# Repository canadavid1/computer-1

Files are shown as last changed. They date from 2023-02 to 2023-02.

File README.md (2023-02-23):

# computer-1
A repository containing documentation, specifications, images and code for my processor built out of discrete 2N7002  transistors.

## Motivation
This project is mostly intended as a learning experience. 

## Directories
### Kicad
Kicad files for all the PCBs used in the project.

NOTICE: some of these have some flaws. Do not rely on these working.
### Assembly
Assorted assembly programs, and the corresponding compiler.
### Emulator
Different levels of emulator for the system.
### Ideas
Ideas for further improvement or additions to the system.

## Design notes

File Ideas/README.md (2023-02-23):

# Ideas
## Extending to 16 bit adressing
Involves adding one register to PC and MARH. Possible problems are jump instructions, as they would not be able to adress all jump-able locations.
## Register rotating
Involves adding a hardware SP (8 byte aligned), and making it such that registers 0-7 are on the stack, and not at locations 0xff0-0xff7. This makes the requirement of pushing and popping values to a semi-software stack much less needed.

To be added: Two registers and INC/DEC circuitry for an SP, and instructions to increment/decrement this. 

- Maybe able to inc/dec using ALU?

- Maybe able to map this SP to a register?

- Should the zero register be moved?
## Proper offset adressing
Currently, loading or storing a value will `or` the register with a four-bit immediate. Make this an offset?

To be added: one adder, two (three if 16 bit adressing) incrementers, some logic

- Maybe: also in JR
## Skip number of words
Currently, skip jumps over one word if the condition is met. Maybe make it jump up to 16 words instead?

To be added: one adder for the lowest register of PC

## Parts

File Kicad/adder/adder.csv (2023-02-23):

Source: | C:\Users\david\OneDrive\Pictures\Documents\KICAD\transistor computer v2\adder\adder.sch
Date: | 23/01/2023 12:58:03
Tool: | Eeschema (5.1.9)-1
Generator: | C:\Program Files\KiCad\bin\scripting\plugins/bom_csv_grouped_by_value.py
Component Count: | 83
Individual Components:
Item | Qty | Reference(s) | Value | LibPart | Footprint | Datasheet
 |  | C0 | C | Device:C | Capacitor_SMD:C_0603_1608Metric_Pad1.08x0.95mm_HandSolder | ~
 |  | D0 | D | Device:D | Diode_SMD:D_SOD-323_HandSoldering | ~
 |  | D1 | D | Device:D | Diode_SMD:D_SOD-323_HandSoldering | ~
 |  | D2 | D | Device:D | Diode_SMD:D_SOD-323_HandSoldering | ~
 |  | D3 | D | Device:D | Diode_SMD:D_SOD-323_HandSoldering | ~
 |  | D4 | D | Device:D | Diode_SMD:D_SOD-323_HandSoldering | ~
 |  | D5 | D | Device:D | Diode_SMD:D_SOD-323_HandSoldering | ~
 |  | D6 | D | Device:D | Diode_SMD:D_SOD-323_HandSoldering | ~
 |  | D7 | D | Device:D | Diode_SMD:D_SOD-323_HandSoldering | ~
 |  | D8 | D | Device:D | Diode_SMD:D_SOD-323_HandSoldering | ~
 |  | D201 | D | Device:D | Diode_SMD:D_SOD-323_HandSoldering | ~
 |  | D202 | D | Device:D | Diode_SMD:D_SOD-323_HandSoldering | ~
 |  | D203 | D | Device:D | Diode_SMD:D_SOD-323_HandSoldering | ~
 |  | D204 | D | Device:D | Diode_SMD:D_SOD-323_HandSoldering | ~
 |  | D205 | D | Device:D | Diode_SMD:D_SOD-323_HandSoldering | ~
 |  | D206 | D | Device:D | Diode_SMD:D_SOD-323_HandSoldering | ~
 |  | D207 | D | Device:D | Diode_SMD:D_SOD-323_HandSoldering | ~
 |  | D208 | D | Device:D | Diode_SMD:D_SOD-323_HandSoldering | ~
 |  | D209 | D | Device:D | Diode_SMD:D_SOD-323_HandSoldering | ~
 |  | D301 | D | Device:D | Diode_SMD:D_SOD-323_HandSoldering | ~
 |  | D302 | D | Device:D | Diode_SMD:D_SOD-323_HandSoldering | ~
 |  | D303 | D | Device:D | Diode_SMD:D_SOD-323_HandSoldering | ~
 |  | D304 | D | Device:D | Diode_SMD:D_SOD-323_HandSoldering | ~
 |  | D305 | D | Device:D | Diode_SMD:D_SOD-323_HandSoldering | ~
 |  | D306 | D | Device:D | Diode_SMD:D_SOD-323_HandSoldering | ~
 |  | D307 | D | Device:D | Diode_SMD:D_SOD-323_HandSoldering | ~
 |  | D308 | D | Device:D | Diode_SMD:D_SOD-323_HandSoldering | ~
 |  | D309 | D | Device:D | Diode_SMD:D_SOD-323_HandSoldering | ~
 |  | D401 | D | Device:D | Diode_SMD:D_SOD-323_HandSoldering | ~
 |  | D402 | D | Device:D | Diode_SMD:D_SOD-323_HandSoldering | ~
 |  | D403 | D | Device:D | Diode_SMD:D_SOD-323_HandSoldering | ~
 |  | D404 | D | Device:D | Diode_SMD:D_SOD-323_HandSoldering | ~
 |  | D405 | D | Device:D | Diode_SMD:D_SOD-323_HandSoldering | ~
 |  | D406 | D | Device:D | Diode_SMD:D_SOD-323_HandSoldering | ~
 |  | D407 | D | Device:D | Diode_SMD:D_SOD-323_HandSoldering | ~
 |  | D408 | D | Device:D | Diode_SMD:D_SOD-323_HandSoldering | ~
 |  | D409 | D | Device:D | Diode_SMD:D_SOD-323_HandSoldering | ~
 |  | Q0 | 2N7002 | Transistor_FET:2N7002 | Package_TO_SOT_SMD:SOT-23 | https://www.onsemi.com/pub/Collateral/NDS7002A-D.PDF
 |  | Q1 | 2N7002 | Transistor_FET:2N7002 | Package_TO_SOT_SMD:SOT-23 | https://www.onsemi.com/pub/Collateral/NDS7002A-D.PDF
 |  | Q2 | 2N7002 | Transistor_FET:2N7002 | Package_TO_SOT_SMD:SOT-23 | https://www.onsemi.com/pub/Collateral/NDS7002A-D.PDF
 |  | Q3 | 2N7002 | Transistor_FET:2N7002 | Package_TO_SOT_SMD:SOT-23 | https://www.onsemi.com/pub/Collateral/NDS7002A-D.PDF
 |  | Q4 | 2N7002 | Transistor_FET:2N7002 | Package_TO_SOT_SMD:SOT-23 | https://www.onsemi.com/pub/Collateral/NDS7002A-D.PDF
 |  | Q5 | 2N7002 | Transistor_FET:2N7002 | Package_TO_SOT_SMD:SOT-23 | https://www.onsemi.com/pub/Collateral/NDS7002A-D.PDF
 |  | Q6 | 2N7002 | Transistor_FET:2N7002 | Package_TO_SOT_SMD:SOT-23 | https://www.onsemi.com/pub/Collateral/NDS7002A-D.PDF
 |  | Q7 | 2N7002 | Transistor_FET:2N7002 | Package_TO_SOT_SMD:SOT-23 | https://www.onsemi.com/pub/Collateral/NDS7002A-D.PDF
 |  | Q8 | 2N7002 | Transistor_FET:2N7002 | Package_TO_SOT_SMD:SOT-23 | https://www.onsemi.com/pub/Collateral/NDS7002A-D.PDF
 |  | Q9 | 2N7002 | Transistor_FET:2N7002 | Package_TO_SOT_SMD:SOT-23 | https://www.onsemi.com/pub/Collateral/NDS7002A-D.PDF
 |  | Q201 | 2N7002 | Transistor_FET:2N7002 | Package_TO_SOT_SMD:SOT-23 | https://www.onsemi.com/pub/Collateral/NDS7002A-D.PDF
 |  | Q202 | 2N7002 | Transistor_FET:2N7002 | Package_TO_SOT_SMD:SOT-23 | https://www.onsemi.com/pub/Collateral/NDS7002A-D.PDF
 |  | Q203 | 2N7002 | Transistor_FET:2N7002 | Package_TO_SOT_SMD:SOT-23 | https://www.onsemi.com/pub/Collateral/NDS7002A-D.PDF
 |  | Q204 | 2N7002 | Transistor_FET:2N7002 | Package_TO_SOT_SMD:SOT-23 | https://www.onsemi.com/pub/Collateral/NDS7002A-D.PDF
 |  | Q205 | 2N7002 | Transistor_FET:2N7002 | Package_TO_SOT_SMD:SOT-23 | https://www.onsemi.com/pub/Collateral/NDS7002A-D.PDF
 |  | Q206 | 2N7002 | Transistor_FET:2N7002 | Package_TO_SOT_SMD:SOT-23 | https://www.onsemi.com/pub/Collateral/NDS7002A-D.PDF
 |  | Q207 | 2N7002 | Transistor_FET:2N7002 | Package_TO_SOT_SMD:SOT-23 | https://www.onsemi.com/pub/Collateral/NDS7002A-D.PDF
 |  | Q208 | 2N7002 | Transistor_FET:2N7002 | Package_TO_SOT_SMD:SOT-23 | https://www.onsemi.com/pub/Collateral/NDS7002A-D.PDF
 |  | Q209 | 2N7002 | Transistor_FET:2N7002 | Package_TO_SOT_SMD:SOT-23 | https://www.onsemi.com/pub/Collateral/NDS7002A-D.PDF
 |  | Q210 | 2N7002 | Transistor_FET:2N7002 | Package_TO_SOT_SMD:SOT-23 | https://www.onsemi.com/pub/Collateral/NDS7002A-D.PDF
 |  | Q301 | 2N7002 | Transistor_FET:2N7002 | Package_TO_SOT_SMD:SOT-23 | https://www.onsemi.com/pub/Collateral/NDS7002A-D.PDF
 |  | Q302 | 2N7002 | Transistor_FET:2N7002 | Package_TO_SOT_SMD:SOT-23 | https://www.onsemi.com/pub/Collateral/NDS7002A-D.PDF
 |  | Q303 | 2N7002 | Transistor_FET:2N7002 | Package_TO_SOT_SMD:SOT-23 | https://www.onsemi.com/pub/Collateral/NDS7002A-D.PDF
 |  | Q304 | 2N7002 | Transistor_FET:2N7002 | Package_TO_SOT_SMD:SOT-23 | https://www.onsemi.com/pub/Collateral/NDS7002A-D.PDF
 |  | Q305 | 2N7002 | Transistor_FET:2N7002 | Package_TO_SOT_SMD:SOT-23 | https://www.onsemi.com/pub/Collateral/NDS7002A-D.PDF
 |  | Q306 | 2N7002 | Transistor_FET:2N7002 | Package_TO_SOT_SMD:SOT-23 | https://www.onsemi.com/pub/Collateral/NDS7002A-D.PDF
 |  | Q307 | 2N7002 | Transistor_FET:2N7002 | Package_TO_SOT_SMD:SOT-23 | https://www.onsemi.com/pub/Collateral/NDS7002A-D.PDF
 |  | Q308 | 2N7002 | Transistor_FET:2N7002 | Package_TO_SOT_SMD:SOT-23 | https://www.onsemi.com/pub/Collateral/NDS7002A-D.PDF
 |  | Q309 | 2N7002 | Transistor_FET:2N7002 | Package_TO_SOT_SMD:SOT-23 | https://www.onsemi.com/pub/Collateral/NDS7002A-D.PDF
 |  | Q310 | 2N7002 | Transistor_FET:2N7002 | Package_TO_SOT_SMD:SOT-23 | https://www.onsemi.com/pub/Collateral/NDS7002A-D.PDF
 |  | Q401 | 2N7002 | Transistor_FET:2N7002 | Package_TO_SOT_SMD:SOT-23 | https://www.onsemi.com/pub/Collateral/NDS7002A-D.PDF
 |  | Q402 | 2N7002 | Transistor_FET:2N7002 | Package_TO_SOT_SMD:SOT-23 | https://www.onsemi.com/pub/Collateral/NDS7002A-D.PDF
 |  | Q403 | 2N7002 | Transistor_FET:2N7002 | Package_TO_SOT_SMD:SOT-23 | https://www.onsemi.com/pub/Collateral/NDS7002A-D.PDF
 |  | Q404 | 2N7002 | Transistor_FET:2N7002 | Package_TO_SOT_SMD:SOT-23 | https://www.onsemi.com/pub/Collateral/NDS7002A-D.PDF
 |  | Q405 | 2N7002 | Transistor_FET:2N7002 | Package_TO_SOT_SMD:SOT-23 | https://www.onsemi.com/pub/Collateral/NDS7002A-D.PDF
 |  | Q406 | 2N7002 | Transistor_FET:2N7002 | Package_TO_SOT_SMD:SOT-23 | https://www.onsemi.com/pub/Collateral/NDS7002A-D.PDF
 |  | Q407 | 2N7002 | Transistor_FET:2N7002 | Package_TO_SOT_SMD:SOT-23 | https://www.onsemi.com/pub/Collateral/NDS7002A-D.PDF
 |  | Q408 | 2N7002 | Transistor_FET:2N7002 | Package_TO_SOT_SMD:SOT-23 | https://www.onsemi.com/pub/Collateral/NDS7002A-D.PDF
 |  | Q409 | 2N7002 | Transistor_FET:2N7002 | Package_TO_SOT_SMD:SOT-23 | https://www.onsemi.com/pub/Collateral/NDS7002A-D.PDF
 |  | Q410 | 2N7002 | Transistor_FET:2N7002 | Package_TO_SOT_SMD:SOT-23 | https://www.onsemi.com/pub/Collateral/NDS7002A-D.PDF
 |  | RN0 | R_Pack04 | Device:R_Pack04 | Resistor_SMD:R_Array_Convex_4x1206 | ~
 |  | RN1 | R_Pack04 | Device:R_Pack04 | Resistor_SMD:R_Array_Convex_4x1206 | ~
 |  | RN2 | R_Pack04 | Device:R_Pack04 | Resistor_SMD:R_Array_Convex_4x1206 | ~
 |  | RN201 | R_Pack04 | Device:R_Pack04 | Resistor_SMD:R_Array_Convex_4x1206 | ~
 |  | RN301 | R_Pack04 | Device:R_Pack04 | Resistor_SMD:R_Array_Convex_4x1206 | ~
 |  | RN401 | R_Pack04 | Device:R_Pack04 | Resistor_SMD:R_Array_Convex_4x1206 | ~
Collated Components:
Item | Qty | Reference(s) | Value | LibPart | Footprint | Datasheet
1 | 1 | C0 | C | Device:C | Capacitor_SMD:C_0603_1608Metric_Pad1.08x0.95mm_HandSolder | ~
2 | 36 | D0, D1, D2, D3, D4, D5, D6, D7, D8, D201, D202, D203, D204, D205, D206, D207, D208, D209, D301, D302, D303, D304, D305, D306, D307, D308, D309, D401, D402, D403, D404, D405, D406, D407, D408, D409 | D | Device:D | Diode_SMD:D_SOD-323_HandSoldering | ~
3 | 40 | Q0, Q1, Q2, Q3, Q4, Q5, Q6, Q7, Q8, Q9, Q201, Q202, Q203, Q204, Q205, Q206, Q207, Q208, Q209, Q210, Q301, Q302, Q303, Q304, Q305, Q306, Q307, Q308, Q309, Q310, Q401, Q402, Q403, Q404, Q405, Q406, Q407, Q408, Q409, Q410 | 2N7002 | Transistor_FET:2N7002 | Package_TO_SOT_SMD:SOT-23 | https://www.onsemi.com/pub/Collateral/NDS7002A-D.PDF
4 | 6 | RN0, RN1, RN2, RN201, RN301, RN401 | R_Pack04 | Device:R_Pack04 | Resistor_SMD:R_Array_Convex_4x1206 | ~

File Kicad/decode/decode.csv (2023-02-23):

Source: | C:\Users\david\OneDrive\Pictures\Documents\KICAD\transistor computer v2\decode\decode.sch
Date: | 23/01/2023 12:58:19
Tool: | Eeschema (5.1.9)-1
Generator: | C:\Program Files\KiCad\bin\scripting\plugins/bom_csv_grouped_by_value.py
Component Count: | 59
Individual Components:
Item | Qty | Reference(s) | Value | LibPart | Footprint | Datasheet
 |  | D0 | D | Device:D | custom:D_SOD-323_HandSoldering | ~
 |  | D1 | D | Device:D | custom:D_SOD-323_HandSoldering | ~
 |  | D2 | D | Device:D | custom:D_SOD-323_HandSoldering | ~
 |  | D3 | D | Device:D | custom:D_SOD-323_HandSoldering | ~
 |  | D4 | D | Device:D | custom:D_SOD-323_HandSoldering | ~
 |  | D5 | D | Device:D | custom:D_SOD-323_HandSoldering | ~
 |  | D6 | D | Device:D | custom:D_SOD-323_HandSoldering | ~
 |  | D7 | D | Device:D | custom:D_SOD-323_HandSoldering | ~
 |  | D10 | D | Device:D | custom:D_SOD-323_HandSoldering | ~
 |  | D11 | D | Device:D | custom:D_SOD-323_HandSoldering | ~
 |  | D12 | D | Device:D | custom:D_SOD-323_HandSoldering | ~
 |  | D13 | D | Device:D | custom:D_SOD-323_HandSoldering | ~
 |  | D14 | D | Device:D | custom:D_SOD-323_HandSoldering | ~
 |  | D15 | D | Device:D | custom:D_SOD-323_HandSoldering | ~
 |  | D16 | D | Device:D | custom:D_SOD-323_HandSoldering | ~
 |  | D17 | D | Device:D | custom:D_SOD-323_HandSoldering | ~
 |  | D20 | D | Device:D | custom:D_SOD-323_HandSoldering | ~
 |  | D21 | D | Device:D | custom:D_SOD-323_HandSoldering | ~
 |  | D22 | D | Device:D | custom:D_SOD-323_HandSoldering | ~
 |  | D23 | D | Device:D | custom:D_SOD-323_HandSoldering | ~
 |  | D24 | D | Device:D | custom:D_SOD-323_HandSoldering | ~
 |  | D25 | D | Device:D | custom:D_SOD-323_HandSoldering | ~
 |  | D26 | D | Device:D | custom:D_SOD-323_HandSoldering | ~
 |  | D27 | D | Device:D | custom:D_SOD-323_HandSoldering | ~
 |  | D30 | D | Device:D | custom:D_SOD-323_HandSoldering | ~
 |  | D31 | D | Device:D | custom:D_SOD-323_HandSoldering | ~
 |  | D32 | D | Device:D | custom:D_SOD-323_HandSoldering | ~
 |  | D33 | D | Device:D | custom:D_SOD-323_HandSoldering | ~
 |  | D34 | D | Device:D | custom:D_SOD-323_HandSoldering | ~
 |  | D35 | D | Device:D | custom:D_SOD-323_HandSoldering | ~
 |  | D36 | D | Device:D | custom:D_SOD-323_HandSoldering | ~
 |  | D37 | D | Device:D | custom:D_SOD-323_HandSoldering | ~
 |  | D40 | D | Device:D | custom:D_SOD-323_HandSoldering | ~
 |  | D41 | D | Device:D | custom:D_SOD-323_HandSoldering | ~
 |  | D42 | D | Device:D | custom:D_SOD-323_HandSoldering | ~
 |  | D43 | D | Device:D | custom:D_SOD-323_HandSoldering | ~
 |  | D44 | D | Device:D | custom:D_SOD-323_HandSoldering | ~
 |  | D45 | D | Device:D | custom:D_SOD-323_HandSoldering | ~
 |  | D46 | D | Device:D | custom:D_SOD-323_HandSoldering | ~
 |  | D47 | D | Device:D | custom:D_SOD-323_HandSoldering | ~
 |  | D50 | D | Device:D | custom:D_SOD-323_HandSoldering | ~
 |  | D51 | D | Device:D | custom:D_SOD-323_HandSoldering | ~
 |  | D52 | D | Device:D | custom:D_SOD-323_HandSoldering | ~
 |  | D53 | D | Device:D | custom:D_SOD-323_HandSoldering | ~
 |  | D54 | D | Device:D | custom:D_SOD-323_HandSoldering | ~
 |  | D55 | D | Device:D | custom:D_SOD-323_HandSoldering | ~
 |  | D56 | D | Device:D | custom:D_SOD-323_HandSoldering | ~
 |  | D57 | D | Device:D | custom:D_SOD-323_HandSoldering | ~
 |  | J0 | Conn_01x04_Male | Connector:Conn_01x04_Male | Connector_PinHeader_2.54mm:PinHeader_1x04_P2.54mm_Vertical | ~
 |  | J1 | Conn_01x04_Male | Connector:Conn_01x04_Male | Connector_PinHeader_2.54mm:PinHeader_1x04_P2.54mm_Vertical | ~
 |  | J2 | Conn_01x06_Male | Connector:Conn_01x06_Male | Connector_PinHeader_2.54mm:PinHeader_1x06_P2.54mm_Vertical | ~
 |  | JP0 | SolderJumper_2_Bridged | Jumper:SolderJumper_2_Bridged | Jumper:SolderJumper-2_P1.3mm_Bridged_RoundedPad1.0x1.5mm | ~
 |  | JP1 | SolderJumper_2_Bridged | Jumper:SolderJumper_2_Bridged | Jumper:SolderJumper-2_P1.3mm_Bridged_RoundedPad1.0x1.5mm | ~
 |  | Q0 | 2N7002 | Transistor_FET:2N7002 | Package_TO_SOT_SMD:SOT-23 | https://www.onsemi.com/pub/Collateral/NDS7002A-D.PDF
 |  | Q1 | 2N7002 | Transistor_FET:2N7002 | Package_TO_SOT_SMD:SOT-23 | https://www.onsemi.com/pub/Collateral/NDS7002A-D.PDF
 |  | Q2 | 2N7002 | Transistor_FET:2N7002 | Package_TO_SOT_SMD:SOT-23 | https://www.onsemi.com/pub/Collateral/NDS7002A-D.PDF
 |  | Q3 | 2N7002 | Transistor_FET:2N7002 | Package_TO_SOT_SMD:SOT-23 | https://www.onsemi.com/pub/Collateral/NDS7002A-D.PDF
 |  | Q4 | 2N7002 | Transistor_FET:2N7002 | Package_TO_SOT_SMD:SOT-23 | https://www.onsemi.com/pub/Collateral/NDS7002A-D.PDF
 |  | Q5 | 2N7002 | Transistor_FET:2N7002 | Package_TO_SOT_SMD:SOT-23 | https://www.onsemi.com/pub/Collateral/NDS7002A-D.PDF
Collated Components:
Item | Qty | Reference(s) | Value | LibPart | Footprint | Datasheet
1 | 48 | D0, D1, D2, D3, D4, D5, D6, D7, D10, D11, D12, D13, D14, D15, D16, D17, D20, D21, D22, D23, D24, D25, D26, D27, D30, D31, D32, D33, D34, D35, D36, D37, D40, D41, D42, D43, D44, D45, D46, D47, D50, D51, D52, D53, D54, D55, D56, D57 | D | Device:D | custom:D_SOD-323_HandSoldering | ~
2 | 2 | J0, J1 | Conn_01x04_Male | Connector:Conn_01x04_Male | Connector_PinHeader_2.54mm:PinHeader_1x04_P2.54mm_Vertical | ~
3 | 1 | J2 | Conn_01x06_Male | Connector:Conn_01x06_Male | Connector_PinHeader_2.54mm:PinHeader_1x06_P2.54mm_Vertical | ~
4 | 2 | JP0, JP1 | SolderJumper_2_Bridged | Jumper:SolderJumper_2_Bridged | Jumper:SolderJumper-2_P1.3mm_Bridged_RoundedPad1.0x1.5mm | ~
5 | 6 | Q0, Q1, Q2, Q3, Q4, Q5 | 2N7002 | Transistor_FET:2N7002 | Package_TO_SOT_SMD:SOT-23 | https://www.onsemi.com/pub/Collateral/NDS7002A-D.PDF

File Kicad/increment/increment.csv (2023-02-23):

Source: | C:\Users\david\OneDrive\Pictures\Documents\KICAD\transistor computer v2\increment\increment.sch
Date: | 23/01/2023 12:58:37
Tool: | Eeschema (5.1.9)-1
Generator: | C:\Program Files\KiCad\bin\scripting\plugins/bom_csv_grouped_by_value.py
Component Count: | 22
Individual Components:
Item | Qty | Reference(s) | Value | LibPart | Footprint | Datasheet
 |  | D1 | D | Device:D | Diode_SMD:D_SOD-323 | ~
 |  | D2 | D | Device:D | Diode_SMD:D_SOD-323 | ~
 |  | D3 | D | Device:D | Diode_SMD:D_SOD-323 | ~
 |  | D4 | D | Device:D | Diode_SMD:D_SOD-323 | ~
 |  | D5 | D | Device:D | Diode_SMD:D_SOD-323 | ~
 |  | D6 | D | Device:D | Diode_SMD:D_SOD-323 | ~
 |  | D7 | D | Device:D | Diode_SMD:D_SOD-323 | ~
 |  | D8 | D | Device:D | Diode_SMD:D_SOD-323 | ~
 |  | J1 | USB_B_Micro | Connector:USB_B_Micro | Connector_USB:USB_Micro-B_Amphenol_10104110_Horizontal | ~
 |  | Q1 | 2N7002 | Transistor_FET:2N7002 | Package_TO_SOT_SMD:SOT-23 | https://www.onsemi.com/pub/Collateral/NDS7002A-D.PDF
 |  | Q2 | 2N7002 | Transistor_FET:2N7002 | Package_TO_SOT_SMD:SOT-23 | https://www.onsemi.com/pub/Collateral/NDS7002A-D.PDF
 |  | Q3 | 2N7002 | Transistor_FET:2N7002 | Package_TO_SOT_SMD:SOT-23 | https://www.onsemi.com/pub/Collateral/NDS7002A-D.PDF
 |  | Q4 | 2N7002 | Transistor_FET:2N7002 | Package_TO_SOT_SMD:SOT-23 | https://www.onsemi.com/pub/Collateral/NDS7002A-D.PDF
 |  | Q5 | 2N7002 | Transistor_FET:2N7002 | Package_TO_SOT_SMD:SOT-23 | https://www.onsemi.com/pub/Collateral/NDS7002A-D.PDF
 |  | Q6 | 2N7002 | Transistor_FET:2N7002 | Package_TO_SOT_SMD:SOT-23 | https://www.onsemi.com/pub/Collateral/NDS7002A-D.PDF
 |  | Q7 | 2N7002 | Transistor_FET:2N7002 | Package_TO_SOT_SMD:SOT-23 | https://www.onsemi.com/pub/Collateral/NDS7002A-D.PDF
 |  | Q8 | 2N7002 | Transistor_FET:2N7002 | Package_TO_SOT_SMD:SOT-23 | https://www.onsemi.com/pub/Collateral/NDS7002A-D.PDF
 |  | Q9 | 2N7002 | Transistor_FET:2N7002 | Package_TO_SOT_SMD:SOT-23 | https://www.onsemi.com/pub/Collateral/NDS7002A-D.PDF
 |  | Q10 | 2N7002 | Transistor_FET:2N7002 | Package_TO_SOT_SMD:SOT-23 | https://www.onsemi.com/pub/Collateral/NDS7002A-D.PDF
 |  | Q11 | 2N7002 | Transistor_FET:2N7002 | Package_TO_SOT_SMD:SOT-23 | https://www.onsemi.com/pub/Collateral/NDS7002A-D.PDF
 |  | Q12 | 2N7002 | Transistor_FET:2N7002 | Package_TO_SOT_SMD:SOT-23 | https://www.onsemi.com/pub/Collateral/NDS7002A-D.PDF
 |  | RN1 | R_Pack04_Split | Device:R_Pack04_Split | Resistor_SMD:R_Array_Convex_4x1206
Collated Components:
Item | Qty | Reference(s) | Value | LibPart | Footprint | Datasheet
1 | 8 | D1, D2, D3, D4, D5, D6, D7, D8 | D | Device:D | Diode_SMD:D_SOD-323 | ~
2 | 1 | J1 | USB_B_Micro | Connector:USB_B_Micro | Connector_USB:USB_Micro-B_Amphenol_10104110_Horizontal | ~
3 | 12 | Q1, Q2, Q3, Q4, Q5, Q6, Q7, Q8, Q9, Q10, Q11, Q12 | 2N7002 | Transistor_FET:2N7002 | Package_TO_SOT_SMD:SOT-23 | https://www.onsemi.com/pub/Collateral/NDS7002A-D.PDF
4 | 1 | RN1 | R_Pack04_Split | Device:R_Pack04_Split | Resistor_SMD:R_Array_Convex_4x1206

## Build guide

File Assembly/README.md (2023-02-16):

# Assembly code and assembler
This directory contains various assembly programs, and the corresponding assembler.
## Programmer's model
The machine is outwardly a RISC mahcine with 15 hardware 16-bit registers, and (for now) 4081 16-bit words of memory. Register zero is permanently 0.

Almost all operations are register-agnostic, with the exception of `jal`, which jumps to the specified location and stores the return address in r15. Avaliable operations are:

The machine has three status bits, which are the `N`egative, `C`arry, and `Z`ero flags. These are set by all arithmetic operations, and also by loads/stores.

Avaliable operations are:

- `add/sub/adc/sbc/and/xor rd,rx,ry` - performs the corresponding arithmetic operation

- `add/sub/adc/sbc/and/xor rd,rx,#imm` - immediate may be any 16-bit value

- `addis/subis rd,rx,#imm` - immediate may be any power of two less than 256. Shorter encoding.

- `ld/st rd,rp,#off` - address is `rp&off`. Note the logical AND, not addition.

- `j/jal ad` - jumps to the 12-bit address. `jal` stores the return address in `r15`

- `jalr rd,rl,#off` - jumps to `rd&off`, storing return address in `rl`

- `in/out ra,p` - takes input (output) from port `p` into register `ra`

- `skp len,#COND` - skips the next `len` bytes depending on flag condition. Len may currently be one of `1` and `2`

There are also several pseudo-instructins:

- `add/sub/adc/sbc/and/xor rd,y/#imm` - `rx`=`rd`

- `addis/subis rd,#imm` - `rx`=`rd`

- `li rd,#val` - `add rd,r0,#val`

- `jr ra` - `jal rd,r0`

- `ret` - `jal r15,r0`

### On `skp` encoding
The `skp` instruction may branch on any combination of `Z`, `N`, and `C`. The control bits multiplex from the 8 bits in `COND`, and branches if corresponding bit is `1`.

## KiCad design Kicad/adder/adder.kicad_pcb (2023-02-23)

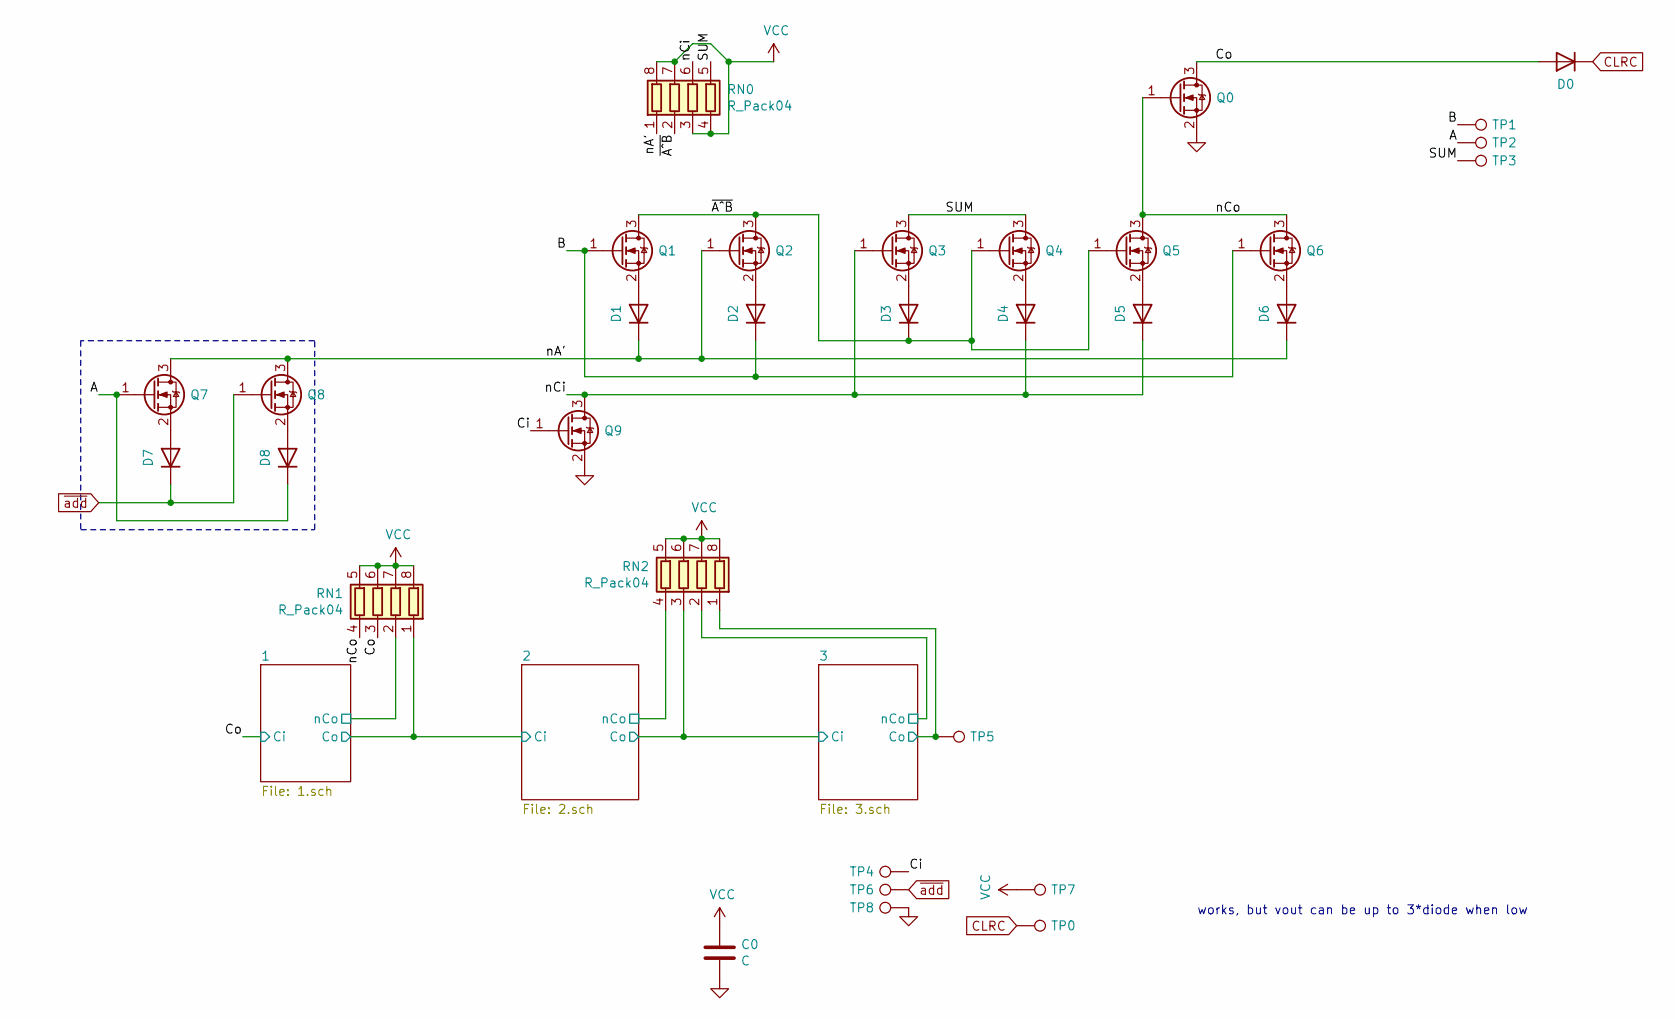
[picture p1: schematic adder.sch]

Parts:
C0: C; C_0603_1608Metric_Pad1.08x0.95mm_HandSolder
D0, D1, D2, D3, D4, D5, D6, D7, D8: D; D_SOD-323_HandSoldering
Q0, Q1, Q2, Q3, Q4, Q5, Q6, Q7, Q8, Q9: 2N7002; SOT-23
RN0, RN1, RN2: R_Pack04; R_Array_Convex_4x1206
TP0, TP1, TP2, TP3, TP4, TP5, TP6, TP7, TP8: Pin_D1.0mm_L10.0mm

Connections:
/1/nCo: RN1.2 (R2.1); also elsewhere on the board
/2/Ci: RN1.1 (R1.1); also elsewhere on the board
/2/nCo: RN2.4 (R4.1); also elsewhere on the board
/3/Ci: RN2.3 (R3.1); also elsewhere on the board
/3/Co: RN2.1 (R1.1), TP5.1; also elsewhere on the board
/3/nCo: RN2.2 (R2.1); also elsewhere on the board
/A: D8.1 (K), Q7.1 (G), TP2.1
/B: D2.1 (K), Q1.1 (G), Q6.1 (G), TP1.1
/Ci: Q9.1 (G), TP4.1
/Co: D0.2 (A), Q0.3 (D), RN1.3 (R3.1); also elsewhere on the board
/SUM: Q3.3 (D), Q4.3 (D), RN0.5 (R4.2), TP3.1
/nA': D1.1 (K), D6.1 (K), Q2.1 (G), Q7.3 (D), Q8.3 (D), RN0.1 (R1.1)
/nCi: D4.1 (K), D5.1 (K), Q3.1 (G), Q9.3 (D), RN0.6 (R3.2)
/nCo: Q0.1 (G), Q5.3 (D), Q6.3 (D), RN1.4 (R4.1)
/~A^B: D3.1 (K), Q1.3 (D), Q2.3 (D), Q4.1 (G), Q5.1 (G), RN0.2 (R2.1)
CLRC: D0.1 (K), TP0.1; also elsewhere on the board
GND: C0.2, Q0.2 (S), Q9.2 (S), TP8.1; also elsewhere on the board
unnamed: D1.2 (A), Q1.2 (S)
unnamed: D2.2 (A), Q2.2 (S)
unnamed: D3.2 (A), Q3.2 (S)
unnamed: D4.2 (A), Q4.2 (S)
unnamed: D5.2 (A), Q5.2 (S)
unnamed: D6.2 (A), Q6.2 (S)
unnamed: D7.2 (A), Q7.2 (S)
unnamed: D8.2 (A), Q8.2 (S)
VCC: C0.1, RN0.3 (R3.1), RN0.4 (R4.1), RN0.7 (R2.2), RN0.8 (R1.2), RN1.5 (R4.2), RN1.6 (R3.2), RN1.7 (R2.2), RN1.8 (R1.2), RN2.5 (R4.2), RN2.6 (R3.2), RN2.7 (R2.2), RN2.8 (R1.2), TP7.1; also elsewhere on the board
~add: D7.1 (K), Q8.1 (G), TP6.1; also elsewhere on the board

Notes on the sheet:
works, but vout can be up to 3*diode when low

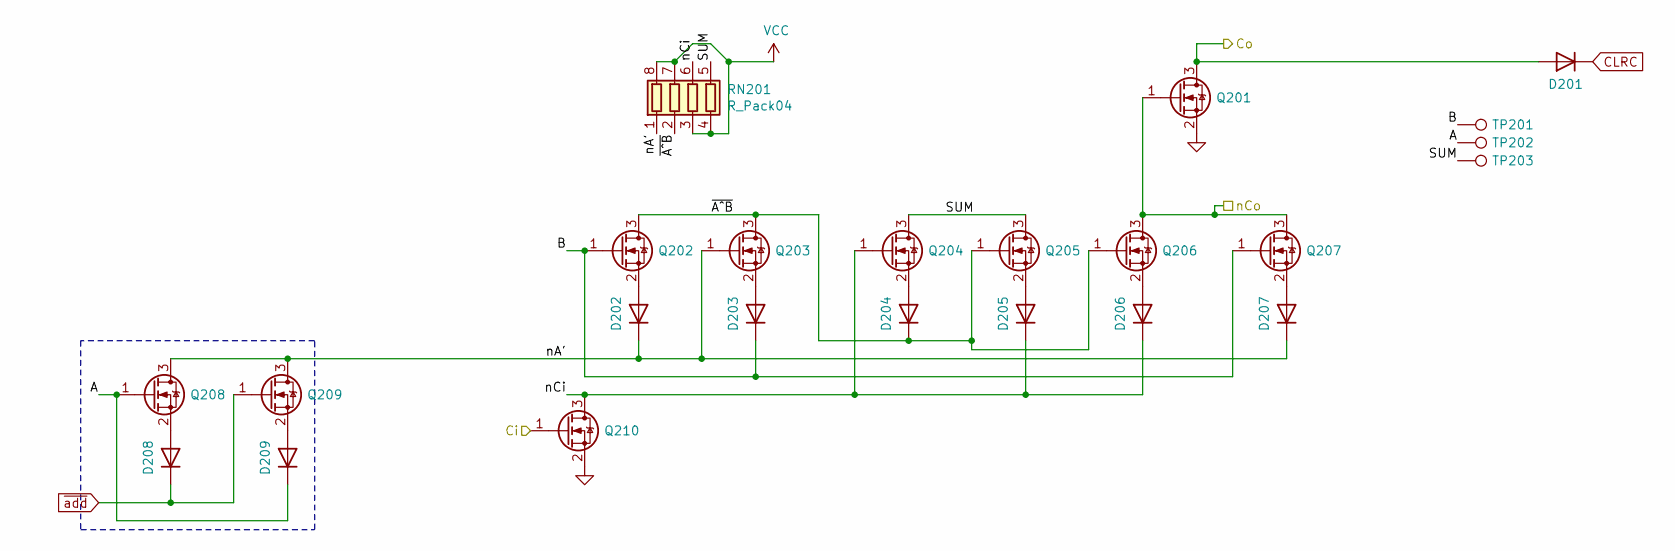
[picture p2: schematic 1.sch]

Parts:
D201, D202, D203, D204, D205, D206, D207, D208, D209: D; D_SOD-323_HandSoldering
Q201, Q202, Q203, Q204, Q205, Q206, Q207, Q208, Q209, Q210: 2N7002; SOT-23
RN201: R_Pack04; R_Array_Convex_4x1206
TP201, TP202, TP203: Pin_D1.0mm_L10.0mm

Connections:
/1/A: D209.1 (K), Q208.1 (G), TP202.1
/1/B: D203.1 (K), Q202.1 (G), Q207.1 (G), TP201.1
/1/SUM: Q204.3 (D), Q205.3 (D), RN201.5 (R4.2), TP203.1
/1/nA': D202.1 (K), D207.1 (K), Q203.1 (G), Q208.3 (D), Q209.3 (D), RN201.1 (R1.1)
/1/nCi: D205.1 (K), D206.1 (K), Q204.1 (G), Q210.3 (D), RN201.6 (R3.2)
/1/nCo: Q201.1 (G), Q206.3 (D), Q207.3 (D); also elsewhere on the board
/1/~A^B: D204.1 (K), Q202.3 (D), Q203.3 (D), Q205.1 (G), Q206.1 (G), RN201.2 (R2.1)
/2/Ci: D201.2 (A), Q201.3 (D); also elsewhere on the board
/Co: Q210.1 (G); also elsewhere on the board
CLRC: D201.1 (K); also elsewhere on the board
GND: Q201.2 (S), Q210.2 (S); also elsewhere on the board
unnamed: D202.2 (A), Q202.2 (S)
unnamed: D203.2 (A), Q203.2 (S)
unnamed: D204.2 (A), Q204.2 (S)
unnamed: D205.2 (A), Q205.2 (S)
unnamed: D206.2 (A), Q206.2 (S)
unnamed: D207.2 (A), Q207.2 (S)
unnamed: D208.2 (A), Q208.2 (S)
unnamed: D209.2 (A), Q209.2 (S)
VCC: RN201.3 (R3.1), RN201.4 (R4.1), RN201.7 (R2.2), RN201.8 (R1.2); also elsewhere on the board
~add: D208.1 (K), Q209.1 (G); also elsewhere on the board

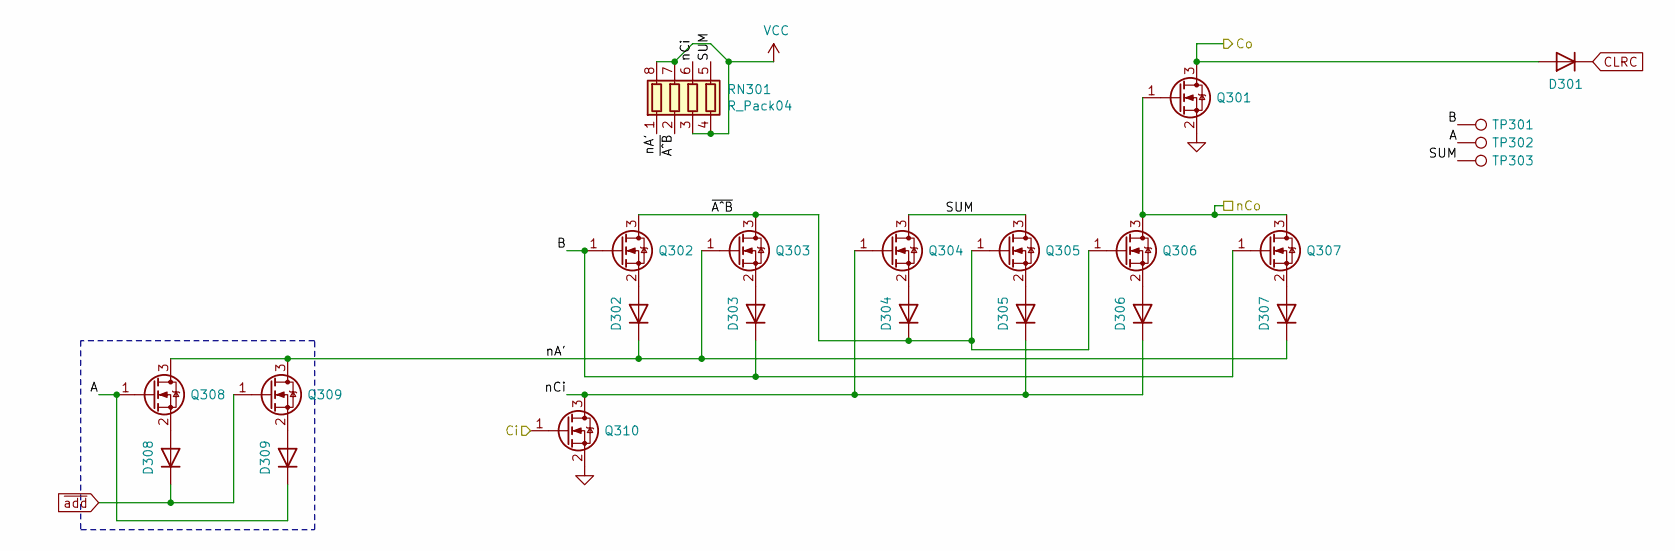
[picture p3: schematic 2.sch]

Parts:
D301, D302, D303, D304, D305, D306, D307, D308, D309: D; D_SOD-323_HandSoldering
Q301, Q302, Q303, Q304, Q305, Q306, Q307, Q308, Q309, Q310: 2N7002; SOT-23
RN301: R_Pack04; R_Array_Convex_4x1206
TP301, TP302, TP303: Pin_D1.0mm_L10.0mm

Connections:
/2/A: D309.1 (K), Q308.1 (G), TP302.1
/2/B: D303.1 (K), Q302.1 (G), Q307.1 (G), TP301.1
/2/Ci: Q310.1 (G); also elsewhere on the board
/2/SUM: Q304.3 (D), Q305.3 (D), RN301.5 (R4.2), TP303.1
/2/nA': D302.1 (K), D307.1 (K), Q303.1 (G), Q308.3 (D), Q309.3 (D), RN301.1 (R1.1)
/2/nCi: D305.1 (K), D306.1 (K), Q304.1 (G), Q310.3 (D), RN301.6 (R3.2)
/2/nCo: Q301.1 (G), Q306.3 (D), Q307.3 (D); also elsewhere on the board
/2/~A^B: D304.1 (K), Q302.3 (D), Q303.3 (D), Q305.1 (G), Q306.1 (G), RN301.2 (R2.1)
/3/Ci: D301.2 (A), Q301.3 (D); also elsewhere on the board
CLRC: D301.1 (K); also elsewhere on the board
GND: Q301.2 (S), Q310.2 (S); also elsewhere on the board
unnamed: D302.2 (A), Q302.2 (S)
unnamed: D303.2 (A), Q303.2 (S)
unnamed: D304.2 (A), Q304.2 (S)
unnamed: D305.2 (A), Q305.2 (S)
unnamed: D306.2 (A), Q306.2 (S)
unnamed: D307.2 (A), Q307.2 (S)
unnamed: D308.2 (A), Q308.2 (S)
unnamed: D309.2 (A), Q309.2 (S)
VCC: RN301.3 (R3.1), RN301.4 (R4.1), RN301.7 (R2.2), RN301.8 (R1.2); also elsewhere on the board
~add: D308.1 (K), Q309.1 (G); also elsewhere on the board

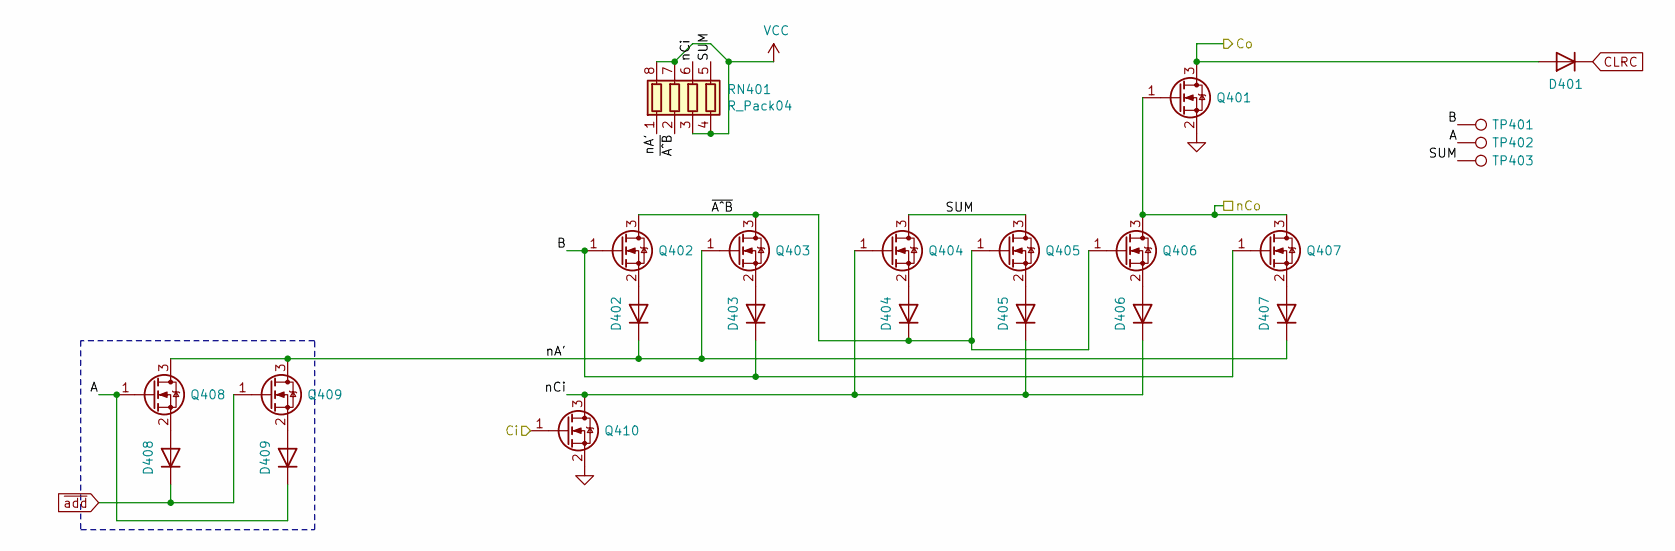
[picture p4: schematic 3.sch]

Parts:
D401, D402, D403, D404, D405, D406, D407, D408, D409: D; D_SOD-323_HandSoldering
Q401, Q402, Q403, Q404, Q405, Q406, Q407, Q408, Q409, Q410: 2N7002; SOT-23
RN401: R_Pack04; R_Array_Convex_4x1206
TP401, TP402, TP403: Pin_D1.0mm_L10.0mm

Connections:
/3/A: D409.1 (K), Q408.1 (G), TP402.1
/3/B: D403.1 (K), Q402.1 (G), Q407.1 (G), TP401.1
/3/Ci: Q410.1 (G); also elsewhere on the board
/3/Co: D401.2 (A), Q401.3 (D); also elsewhere on the board
/3/SUM: Q404.3 (D), Q405.3 (D), RN401.5 (R4.2), TP403.1
/3/nA': D402.1 (K), D407.1 (K), Q403.1 (G), Q408.3 (D), Q409.3 (D), RN401.1 (R1.1)
/3/nCi: D405.1 (K), D406.1 (K), Q404.1 (G), Q410.3 (D), RN401.6 (R3.2)
/3/nCo: Q401.1 (G), Q406.3 (D), Q407.3 (D); also elsewhere on the board
/3/~A^B: D404.1 (K), Q402.3 (D), Q403.3 (D), Q405.1 (G), Q406.1 (G), RN401.2 (R2.1)
CLRC: D401.1 (K); also elsewhere on the board
GND: Q401.2 (S), Q410.2 (S); also elsewhere on the board
unnamed: D402.2 (A), Q402.2 (S)
unnamed: D403.2 (A), Q403.2 (S)
unnamed: D404.2 (A), Q404.2 (S)
unnamed: D405.2 (A), Q405.2 (S)
unnamed: D406.2 (A), Q406.2 (S)
unnamed: D407.2 (A), Q407.2 (S)
unnamed: D408.2 (A), Q408.2 (S)
unnamed: D409.2 (A), Q409.2 (S)
VCC: RN401.3 (R3.1), RN401.4 (R4.1), RN401.7 (R2.2), RN401.8 (R1.2); also elsewhere on the board
~add: D408.1 (K), Q409.1 (G); also elsewhere on the board

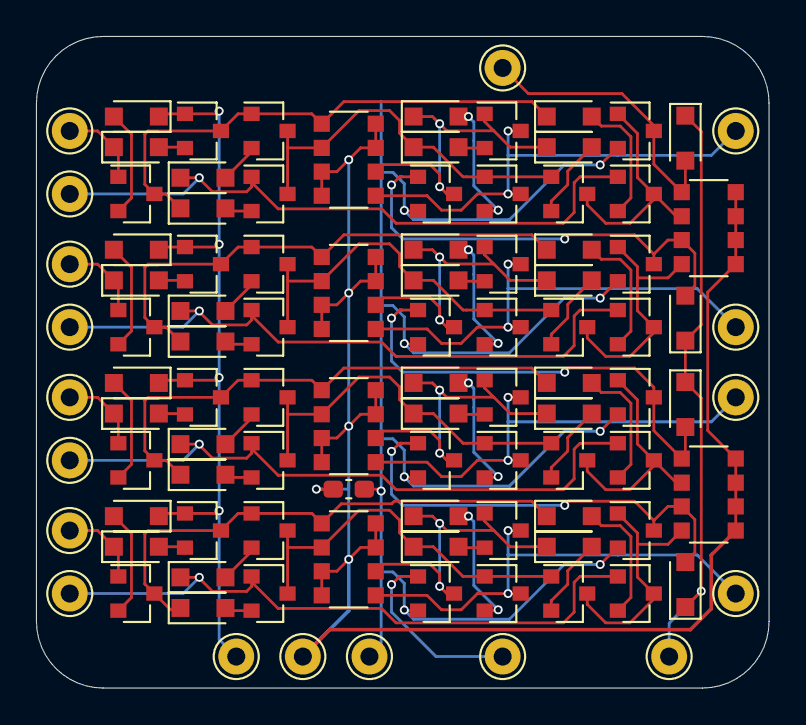
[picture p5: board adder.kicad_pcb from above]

Board: 2 copper layers, 40.7 x 36.2 mm, 101 parts (0 on the bottom side), 69 nets.

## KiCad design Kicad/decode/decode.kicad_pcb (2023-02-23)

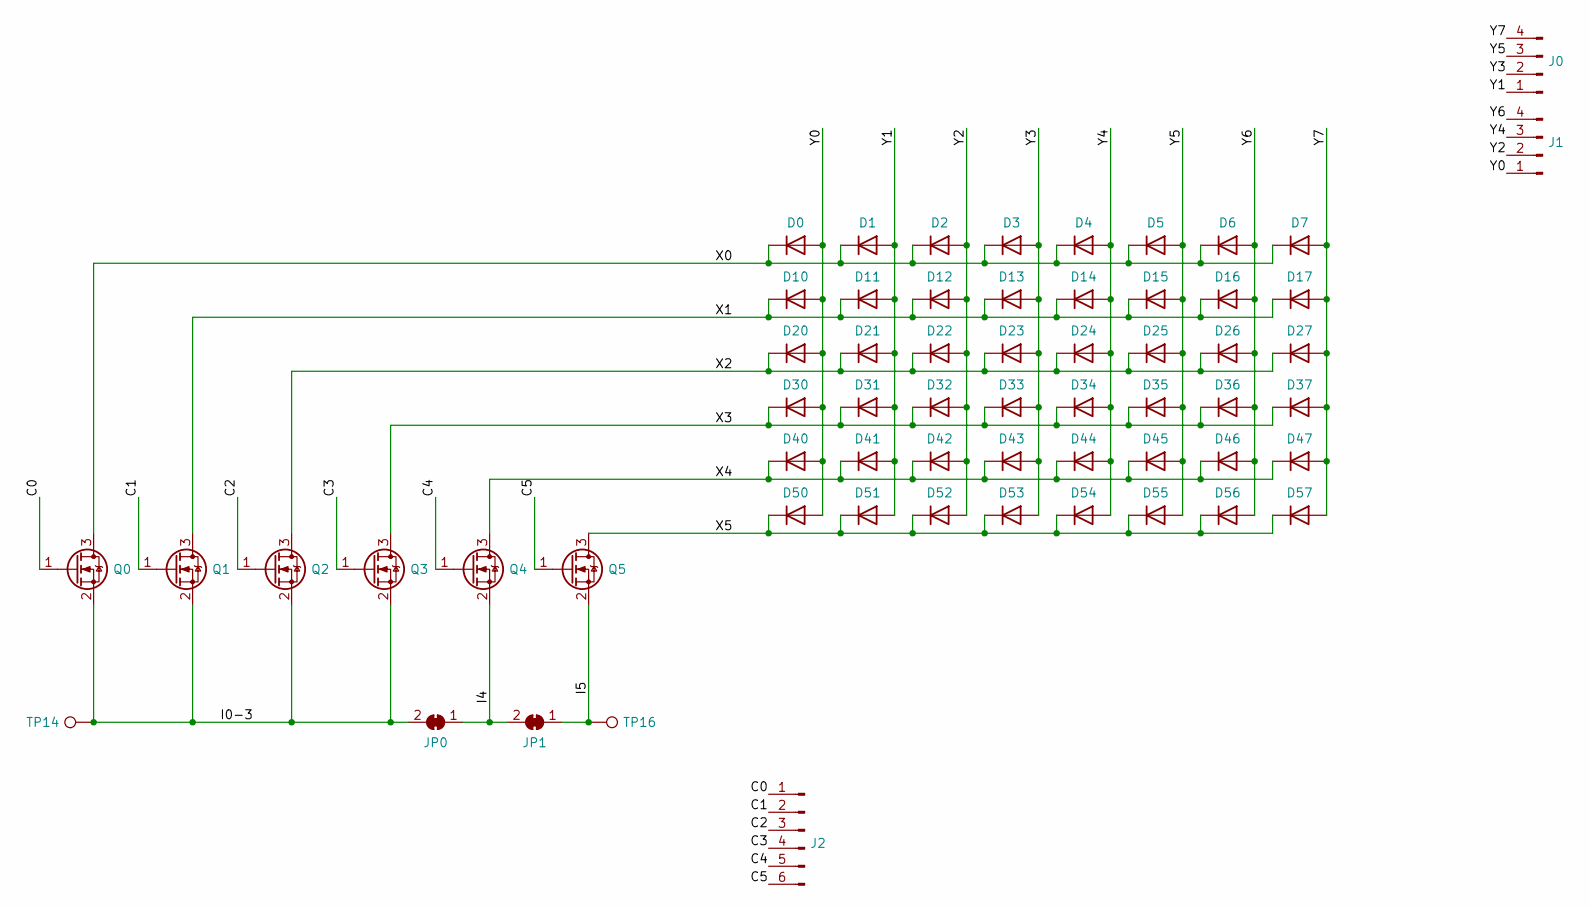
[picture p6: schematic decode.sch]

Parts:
D0, D1, D2, D3, D4, D5, D6, D7, D10, D11, D12, D13, D14, D15, D16, D17, D20, D21, D22, D23, D24, D25, D26, D27, D30, D31, D32, D33, D34, D35, D36, D37, D40, D41, D42, D43, D44, D45, D46, D47, D50, D51, D52, D53, D54, D55, D56, D57: D; D_SOD-323_HandSoldering
J0, J1: Conn_01x04_Male; PinHeader_1x04_P2.54mm_Vertical
J2: Conn_01x06_Male; PinHeader_1x06_P2.54mm_Vertical
JP0, JP1: SolderJumper_2_Bridged; SolderJumper-2_P1.3mm_Bridged_RoundedPad1.0x1.5mm
Q0, Q1, Q2, Q3, Q4, Q5: 2N7002; SOT-23
TP14, TP16: TestPoint; Pin_D1.0mm_L10.0mm

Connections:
/C0: J2.1, Q0.1 (G)
/C1: J2.2, Q1.1 (G)
/C2: J2.3, Q2.1 (G)
/C3: J2.4, Q3.1 (G)
/C4: J2.5, Q4.1 (G)
/C5: J2.6, Q5.1 (G)
/I0-3: JP0.2 (B), Q0.2 (S), Q1.2 (S), Q2.2 (S), Q3.2 (S), TP14.1
/I4: JP0.1 (A), JP1.2 (B), Q4.2 (S)
/I5: JP1.1 (A), Q5.2 (S), TP16.1
/X0: D0.1 (K), D1.1 (K), D2.1 (K), D3.1 (K), D4.1 (K), D5.1 (K), D6.1 (K), D7.1 (K), Q0.3 (D)
/X1: D10.1 (K), D11.1 (K), D12.1 (K), D13.1 (K), D14.1 (K), D15.1 (K), D16.1 (K), D17.1 (K), Q1.3 (D)
/X2: D20.1 (K), D21.1 (K), D22.1 (K), D23.1 (K), D24.1 (K), D25.1 (K), D26.1 (K), D27.1 (K), Q2.3 (D)
/X3: D30.1 (K), D31.1 (K), D32.1 (K), D33.1 (K), D34.1 (K), D35.1 (K), D36.1 (K), D37.1 (K), Q3.3 (D)
/X4: D40.1 (K), D41.1 (K), D42.1 (K), D43.1 (K), D44.1 (K), D45.1 (K), D46.1 (K), D47.1 (K), Q4.3 (D)
/X5: D50.1 (K), D51.1 (K), D52.1 (K), D53.1 (K), D54.1 (K), D55.1 (K), D56.1 (K), D57.1 (K), Q5.3 (D)
/Y0: D0.2 (A), D10.2 (A), D20.2 (A), D30.2 (A), D40.2 (A), D50.2 (A), J1.1
/Y1: D1.2 (A), D11.2 (A), D21.2 (A), D31.2 (A), D41.2 (A), D51.2 (A), J0.1
/Y2: D2.2 (A), D12.2 (A), D22.2 (A), D32.2 (A), D42.2 (A), D52.2 (A), J1.2
/Y3: D3.2 (A), D13.2 (A), D23.2 (A), D33.2 (A), D43.2 (A), D53.2 (A), J0.2
/Y4: D4.2 (A), D14.2 (A), D24.2 (A), D34.2 (A), D44.2 (A), D54.2 (A), J1.3
/Y5: D5.2 (A), D15.2 (A), D25.2 (A), D35.2 (A), D45.2 (A), D55.2 (A), J0.3
/Y6: D6.2 (A), D16.2 (A), D26.2 (A), D36.2 (A), D46.2 (A), D56.2 (A), J1.4
/Y7: D7.2 (A), D17.2 (A), D27.2 (A), D37.2 (A), D47.2 (A), D57.2 (A), J0.4

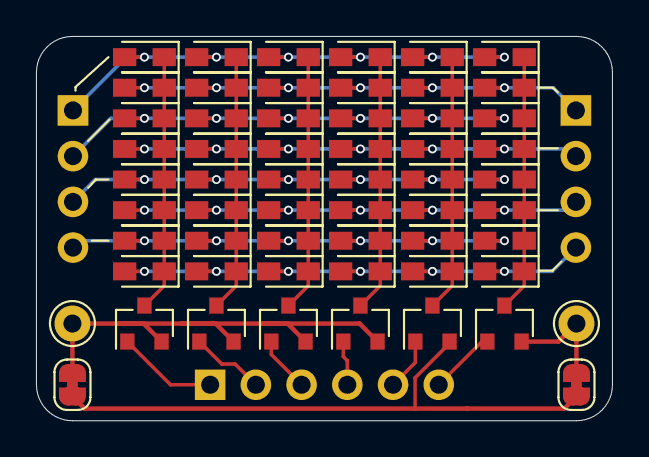
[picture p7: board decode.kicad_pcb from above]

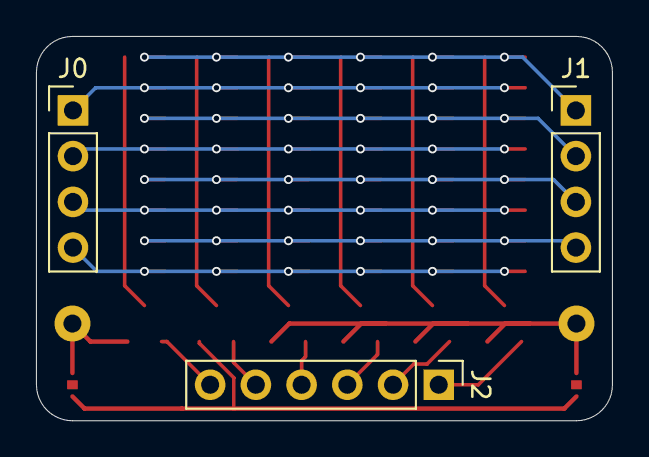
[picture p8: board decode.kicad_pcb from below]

Board: 2 copper layers, 32.0 x 21.3 mm, 61 parts (3 on the bottom side), 23 nets.

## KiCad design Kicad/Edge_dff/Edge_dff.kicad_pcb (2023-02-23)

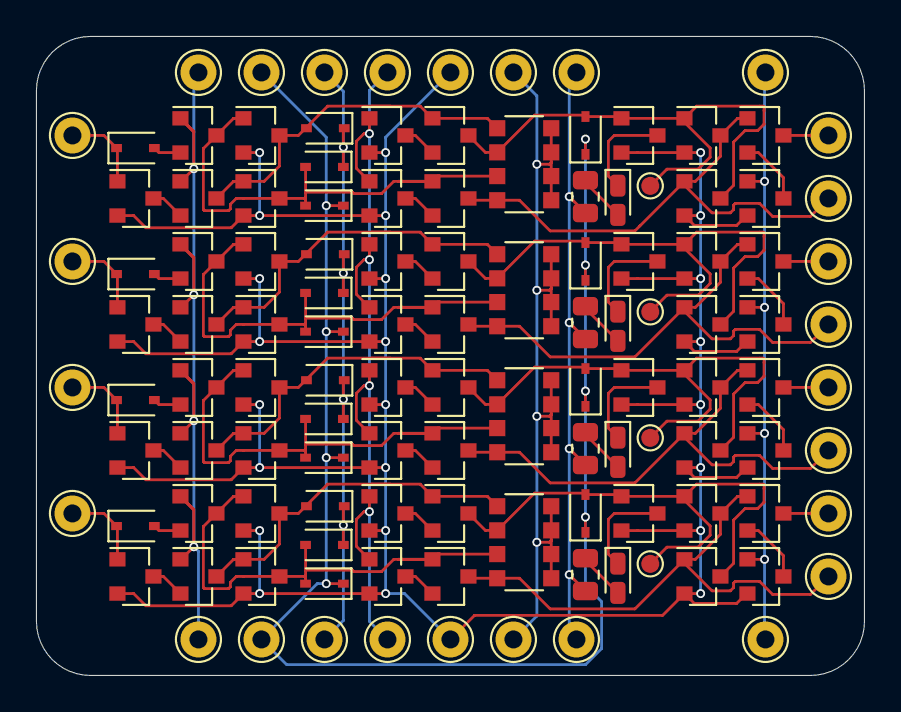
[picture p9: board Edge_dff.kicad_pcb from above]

Board: 2 copper layers, 46.0 x 35.5 mm, 120 parts (0 on the bottom side), 60 nets.

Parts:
D201, D202, D203, D204, D205, D301, D302, D303, D304, D305, D401, D402, D403, D404, D405, D501, D502, D503, D504, D505: D; D_SOD-323
D206, D306, D406, D506: LED; LED_0603_1608Metric_Castellated
Q201, Q202, Q203, Q204, Q205, Q206, Q207, Q208, Q209, Q210, Q211, Q212, Q213, Q214, Q301, Q302, Q303, Q304, Q305, Q306, Q307, Q308, Q309, Q310, Q311, Q312, Q313, Q314, Q401, Q402, Q403, Q404, Q405, Q406, Q407, Q408, Q409, Q410, Q411, Q412, Q413, Q414, Q501, Q502, Q503, Q504, Q505, Q506, Q507, Q508, Q509, Q510, Q511, Q512, Q513, Q514: 2N7002; SOT-23
R201, R301, R401, R501: R; R_0805_2012Metric
RN201, RN301, RN401, RN501: R_Pack04; R_Array_Convex_4x1206
TP102, TP103, TP104, TP105, TP106, TP107, TP108, TP110, TP112, TP113, TP114, TP115, TP116, TP117, TP118, TP120, TP201, TP202, TP203, TP301, TP302, TP303, TP401, TP402, TP403, TP501, TP502, TP503: Pin_D1.0mm_L10.0mm
TP204, TP304, TP404, TP504: TestPoint_Pad_D1.0mm

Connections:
/one/B0: D301.1, Q303.1, TP301.1
/one/B0': Q313.3, TP302.1
/one/I0: D303.2, D304.2, Q301.3, Q304.1, Q305.3, Q306.1, RN301.3
/one/I0': D302.2, Q302.3, Q304.3, Q305.1, Q308.1, RN301.1
/one/Q0: D305.2, Q308.3, Q310.1, Q311.3, Q312.1, RN301.2, TP304.1
/one/Q0': Q306.3, Q310.3, Q311.1, Q313.1, RN301.4, TP303.1
/three/B0: D501.1, Q503.1, TP501.1
/three/B0': Q513.3, TP502.1
/three/I0: D503.2, D504.2, Q501.3, Q504.1, Q505.3, Q506.1, RN501.3
/three/I0': D502.2, Q502.3, Q504.3, Q505.1, Q508.1, RN501.1
/three/Q0: D505.2, Q508.3, Q510.1, Q511.3, Q512.1, RN501.2, TP504.1
/three/Q0': Q506.3, Q510.3, Q511.1, Q513.1, RN501.4, TP503.1
/two/B0: D401.1, Q403.1, TP401.1
/two/B0': Q413.3, TP402.1
/two/I0: D403.2, D404.2, Q401.3, Q404.1, Q405.3, Q406.1, RN401.3
/two/I0': D402.2, Q402.3, Q404.3, Q405.1, Q408.1, RN401.1
/two/Q0: D405.2, Q408.3, Q410.1, Q411.3, Q412.1, RN401.2, TP404.1
/two/Q0': Q406.3, Q410.3, Q411.1, Q413.1, RN401.4, TP403.1
/zero/B0: D201.1, Q203.1, TP201.1
/zero/B0': Q213.3, TP202.1
/zero/I0: D203.2, D204.2, Q201.3, Q204.1, Q205.3, Q206.1, RN201.3
/zero/I0': D202.2, Q202.3, Q204.3, Q205.1, Q208.1, RN201.1
/zero/Q0: D205.2, Q208.3, Q210.1, Q211.3, Q212.1, RN201.2, TP204.1
/zero/Q0': Q206.3, Q210.3, Q211.1, Q213.1, RN201.4, TP203.1
E: D202.1, D203.1, D302.1, D303.1, D402.1, D403.1, D502.1, D503.1, TP106.1, TP116.1
GND: Q203.2, Q204.2, Q205.2, Q207.2, Q209.2, Q210.2, Q211.2, Q212.2, Q214.2, Q303.2, Q304.2, Q305.2, Q307.2, Q309.2, Q310.2, Q311.2, Q312.2, Q314.2, Q403.2, Q404.2, Q405.2, Q407.2, Q409.2, Q410.2, Q411.2, Q412.2, Q414.2, Q503.2, Q504.2, Q505.2, Q507.2, Q509.2, Q510.2, Q511.2, Q512.2, Q514.2, TP110.1, TP120.1
unnamed: D201.2, Q201.2
unnamed: D206.1, Q212.3
unnamed: D206.2, R201.2
unnamed: D301.2, Q301.2
unnamed: D306.1, Q312.3
unnamed: D306.2, R301.2
unnamed: D401.2, Q401.2
unnamed: D406.1, Q412.3
unnamed: D406.2, R401.2
unnamed: D501.2, Q501.2
unnamed: D506.1, Q512.3
unnamed: D506.2, R501.2
unnamed: Q202.2, Q203.3
unnamed: Q206.2, Q207.3
unnamed: Q208.2, Q209.3
unnamed: Q213.2, Q214.3
unnamed: Q302.2, Q303.3
unnamed: Q306.2, Q307.3
unnamed: Q308.2, Q309.3
unnamed: Q313.2, Q314.3
unnamed: Q402.2, Q403.3
unnamed: Q406.2, Q407.3
unnamed: Q408.2, Q409.3
unnamed: Q413.2, Q414.3
unnamed: Q502.2, Q503.3
unnamed: Q506.2, Q507.3
unnamed: Q508.2, Q509.3
unnamed: Q513.2, Q514.3
VCC: RN201.5, RN201.6, RN201.7, RN201.8, RN301.5, RN301.6, RN301.7, RN301.8, RN401.5, RN401.6, RN401.7, RN401.8, RN501.5, RN501.6, RN501.7, RN501.8, TP108.1, TP118.1
Vdrive: R201.1, R301.1, R401.1, R501.1, TP107.1, TP117.1
phi1: Q201.1, Q202.1, Q301.1, Q302.1, Q401.1, Q402.1, Q501.1, Q502.1, TP104.1, TP114.1
phi2: Q207.1, Q209.1, Q307.1, Q309.1, Q407.1, Q409.1, Q507.1, Q509.1, TP103.1, TP113.1
~OE: Q214.1, Q314.1, Q414.1, Q514.1, TP102.1, TP112.1
~reset: D204.1, D205.1, D304.1, D305.1, D404.1, D405.1, D504.1, D505.1, TP105.1, TP115.1

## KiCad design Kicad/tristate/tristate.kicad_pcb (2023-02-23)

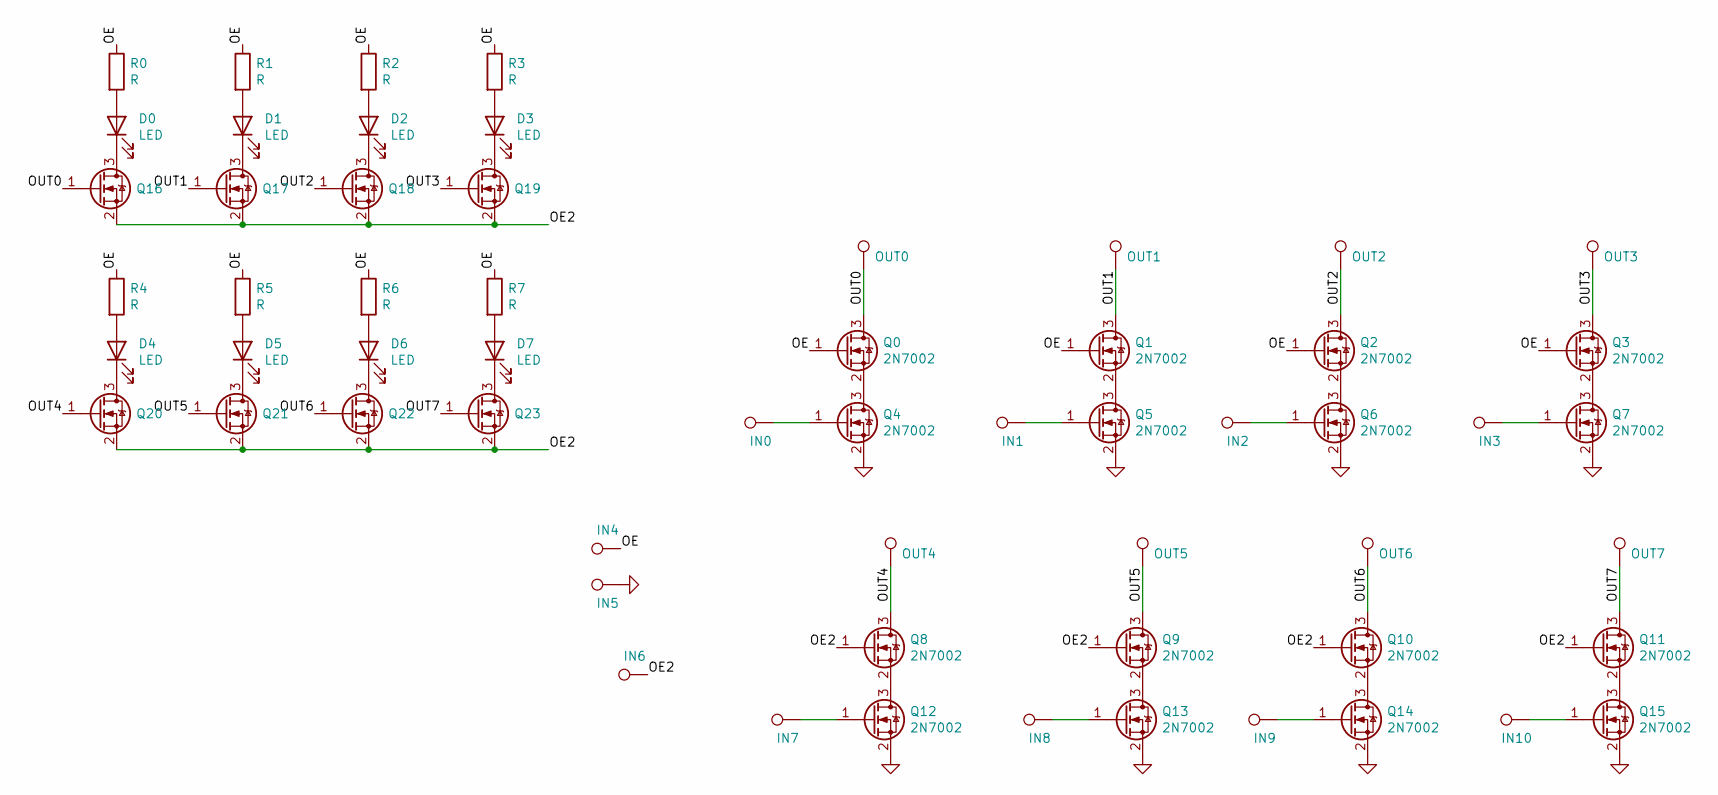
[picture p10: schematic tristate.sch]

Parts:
D0, D1, D2, D3, D4, D5, D6, D7: LED; LED_0603_1608Metric_Pad1.05x0.95mm_HandSolder
IN0, IN1, IN2, IN3, IN4, IN5, IN6, IN7, IN8, IN9, IN10: Pin_D1.0mm_L10.0mm
OUT0, OUT1, OUT2, OUT3, OUT4, OUT5, OUT6, OUT7: Pin_D1.0mm_L10.0mm
Q0, Q1, Q2, Q3, Q4, Q5, Q6, Q7, Q8, Q9, Q10, Q11, Q12, Q13, Q14, Q15, Q16, Q17, Q18, Q19, Q20, Q21, Q22, Q23: 2N7002; SOT-23
R0, R1, R2, R3, R4, R5, R6, R7: R; R_0603_1608Metric_Pad0.98x0.95mm_HandSolder

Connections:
/OE: IN4.1, Q0.1 (G), Q1.1 (G), Q2.1 (G), Q3.1 (G), R0.1, R1.1, R2.1, R3.1, R4.1, R5.1, R6.1, R7.1
/OE2: IN6.1, Q8.1 (G), Q9.1 (G), Q10.1 (G), Q11.1 (G), Q16.2 (S), Q17.2 (S), Q18.2 (S), Q19.2 (S), Q20.2 (S), Q21.2 (S), Q22.2 (S), Q23.2 (S)
/OUT0: OUT0.1, Q0.3 (D), Q16.1 (G)
/OUT1: OUT1.1, Q1.3 (D), Q17.1 (G)
/OUT2: OUT2.1, Q2.3 (D), Q18.1 (G)
/OUT3: OUT3.1, Q3.3 (D), Q19.1 (G)
/OUT4: OUT4.1, Q8.3 (D), Q20.1 (G)
/OUT5: OUT5.1, Q9.3 (D), Q21.1 (G)
/OUT6: OUT6.1, Q10.3 (D), Q22.1 (G)
/OUT7: OUT7.1, Q11.3 (D), Q23.1 (G)
GND: IN5.1, Q4.2 (S), Q5.2 (S), Q6.2 (S), Q7.2 (S), Q12.2 (S), Q13.2 (S), Q14.2 (S), Q15.2 (S)
unnamed: D0.1 (K), Q16.3 (D)
unnamed: D0.2 (A), R0.2
unnamed: D1.1 (K), Q17.3 (D)
unnamed: D1.2 (A), R1.2
unnamed: D2.1 (K), Q18.3 (D)
unnamed: D2.2 (A), R2.2
unnamed: D3.1 (K), Q19.3 (D)
unnamed: D3.2 (A), R3.2
unnamed: D4.1 (K), Q20.3 (D)
unnamed: D4.2 (A), R4.2
unnamed: D5.1 (K), Q21.3 (D)
unnamed: D5.2 (A), R5.2
unnamed: D6.1 (K), Q22.3 (D)
unnamed: D6.2 (A), R6.2
unnamed: D7.1 (K), Q23.3 (D)
unnamed: D7.2 (A), R7.2
unnamed: IN0.1, Q4.1 (G)
unnamed: IN1.1, Q5.1 (G)
unnamed: IN2.1, Q6.1 (G)
unnamed: IN3.1, Q7.1 (G)
unnamed: IN7.1, Q12.1 (G)
unnamed: IN8.1, Q13.1 (G)
unnamed: IN9.1, Q14.1 (G)
unnamed: IN10.1, Q15.1 (G)
unnamed: Q0.2 (S), Q4.3 (D)
unnamed: Q1.2 (S), Q5.3 (D)
unnamed: Q2.2 (S), Q6.3 (D)
unnamed: Q3.2 (S), Q7.3 (D)
unnamed: Q10.2 (S), Q14.3 (D)
unnamed: Q11.2 (S), Q15.3 (D)
unnamed: Q8.2 (S), Q12.3 (D)
unnamed: Q9.2 (S), Q13.3 (D)

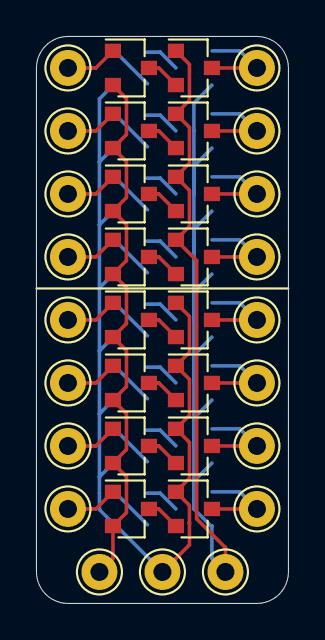
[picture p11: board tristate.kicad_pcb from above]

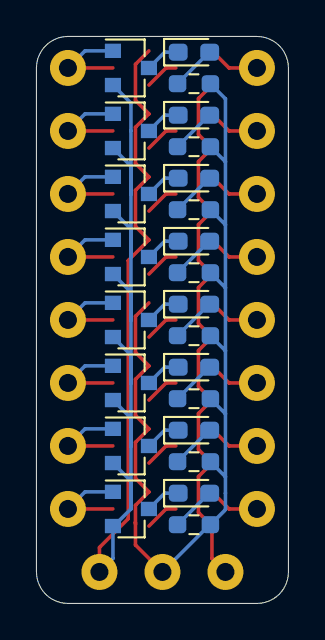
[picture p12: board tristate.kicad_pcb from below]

Board: 2 copper layers, 14.0 x 31.5 mm, 59 parts (24 on the bottom side), 43 nets.

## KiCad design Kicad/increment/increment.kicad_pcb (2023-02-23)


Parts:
D1, D2, D3, D4, D5, D6, D7, D8: D; D_SOD-323
J1: USB_B_Micro; USB_Micro-B_Amphenol_10104110_Horizontal
Q1, Q2, Q3, Q4, Q5, Q6, Q7, Q8, Q9, Q10, Q11, Q12: 2N7002; SOT-23
RN1: R_Pack04_Split; R_Array_Convex_4x1206
TP1, TP2, TP3, TP4, TP5, TP6, TP7, TP8, TP9, TP10, TP11, TP12: TestPoint; Pin_D1.0mm_L10.0mm

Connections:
/I0: D8.1 (K), Q4.1 (G), TP4.1
/I1: D6.1 (K), Q3.1 (G), TP3.1
/I2: D4.1 (K), Q2.1 (G), TP2.1
/I3: D2.1 (K), Q1.1 (G), TP1.1
/O0: J1.2 (D-), Q12.3 (D), TP12.1
/O1: J1.3 (D+), Q11.3 (D), TP11.1
/O2: J1.4 (ID), Q10.3 (D), TP10.1
/O3: J1.5 (GND), J1.6 (Shield), Q9.3 (D), TP9.1
/OE: Q9.1 (G), Q10.1 (G), Q11.1 (G), Q12.1 (G), TP8.1
/~Ci: Q4.2 (S), Q8.1 (G), TP7.1
/~Co: D1.1 (K), J1.1 (VBUS), Q1.3 (D), RN1.8 (R1.2), TP6.1
unnamed: D1.2 (A), Q5.3 (D), Q9.2 (S)
unnamed: D2.2 (A), Q5.2 (S)
unnamed: D3.1 (K), Q1.2 (S), Q2.3 (D), Q5.1 (G), RN1.7 (R2.2)
unnamed: D3.2 (A), Q6.3 (D), Q10.2 (S)
unnamed: D4.2 (A), Q6.2 (S)
unnamed: D5.1 (K), Q2.2 (S), Q3.3 (D), Q6.1 (G), RN1.6 (R3.2)
unnamed: D5.2 (A), Q7.3 (D), Q11.2 (S)
unnamed: D6.2 (A), Q7.2 (S)
unnamed: D7.1 (K), Q3.2 (S), Q4.3 (D), Q7.1 (G), RN1.5 (R4.2)
unnamed: D7.2 (A), Q8.3 (D), Q12.2 (S)
unnamed: D8.2 (A), Q8.2 (S)
VCC: RN1.1 (R1.1), RN1.2 (R2.1), RN1.3 (R3.1), RN1.4 (R4.1), TP5.1


Board: 2 copper layers, 22.8 x 22.8 mm, 34 parts (1 on the bottom side), 23 nets.

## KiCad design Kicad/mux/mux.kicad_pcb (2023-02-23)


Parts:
J1: Conn_01x08_Male; PinHeader_1x08_P2.54mm_Vertical
J2: Conn_01x06_Male; PinHeader_1x06_P2.54mm_Vertical
Q1, Q2, Q3, Q4, Q5, Q6, Q7, Q8, Q9, Q10, Q11, Q12, Q13, Q14, Q15, Q16, Q17, Q18, Q19, Q20, Q21, Q22, Q23, Q24, Q25, Q26, Q27, Q28, Q29, Q30, Q31, Q32, Q33, Q34: 2N7002; SOT-23
RN1, RN2: R_Pack04_Split; R_Array_Convex_4x1206

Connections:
/A: J2.4, Q2.1 (G), Q4.1 (G), Q6.1 (G), Q8.1 (G), Q9.1 (G), Q24.1 (G), Q28.1 (G), Q30.1 (G), Q32.1 (G), Q34.1 (G)
/B: J2.5, Q10.1 (G), Q13.1 (G), Q15.1 (G), Q21.1 (G), Q23.1 (G), Q25.1 (G)
/C: J2.6, Q11.1 (G), Q17.1 (G), Q19.1 (G), Q26.1 (G)
/Q: J2.3, Q16.2 (S), Q17.2 (S), Q18.3 (D), Q19.3 (D), RN2.4 (R4.1)
/Q0: J1.1, Q1.3 (D), Q27.2 (S)
/Q1: J1.2, Q2.3 (D), Q28.2 (S)
/Q2: J1.3, Q3.3 (D), Q29.2 (S)
/Q3: J1.4, Q4.3 (D), Q30.2 (S)
/Q4: J1.5, Q5.3 (D), Q31.2 (S)
/Q5: J1.6, Q6.3 (D), Q32.2 (S)
/Q6: J1.7, Q7.3 (D), Q33.2 (S)
/Q7: J1.8, Q8.3 (D), Q34.2 (S)
/~A: Q1.1 (G), Q3.1 (G), Q5.1 (G), Q7.1 (G), Q9.3 (D), RN1.3 (R3.1)
/~A': Q24.3 (D), Q27.1 (G), Q29.1 (G), Q31.1 (G), Q33.1 (G), RN2.1 (R1.1)
/~B: Q10.3 (D), Q12.1 (G), Q14.1 (G), RN1.2 (R2.1)
/~B': Q20.1 (G), Q22.1 (G), Q25.3 (D), RN2.2 (R2.1)
/~C: Q11.3 (D), Q16.1 (G), RN1.1 (R1.1)
/~C': Q18.1 (G), Q26.3 (D), RN2.3 (R3.1)
GND: J2.2, Q9.2 (S), Q10.2 (S), Q11.2 (S), Q24.2 (S), Q25.2 (S), Q26.2 (S)
unnamed: Q1.2 (S), Q2.2 (S), Q12.3 (D)
unnamed: Q12.2 (S), Q13.2 (S), Q16.3 (D)
unnamed: Q3.2 (S), Q4.2 (S), Q13.3 (D)
unnamed: Q14.2 (S), Q15.2 (S), Q17.3 (D)
unnamed: Q5.2 (S), Q6.2 (S), Q14.3 (D)
unnamed: Q7.2 (S), Q8.2 (S), Q15.3 (D)
unnamed: Q18.2 (S), Q20.3 (D), Q21.3 (D)
unnamed: Q19.2 (S), Q22.3 (D), Q23.3 (D)
unnamed: Q20.2 (S), Q27.3 (D), Q28.3 (D)
unnamed: Q21.2 (S), Q29.3 (D), Q30.3 (D)
unnamed: Q22.2 (S), Q31.3 (D), Q32.3 (D)
unnamed: Q23.2 (S), Q33.3 (D), Q34.3 (D)
VCC: J2.1, RN1.6 (R3.2), RN1.7 (R2.2), RN1.8 (R1.2), RN2.5 (R4.2), RN2.6 (R3.2), RN2.7 (R2.2), RN2.8 (R1.2)

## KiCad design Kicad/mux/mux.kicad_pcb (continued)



Board: 2 copper layers, 20.3 x 26.7 mm, 38 parts (20 on the bottom side), 32 nets.

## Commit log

2023-02-16 Added README for Assembly.
2023-02-23 Added KICAD files.
    [1.sch, 2.sch, 3.sch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]
